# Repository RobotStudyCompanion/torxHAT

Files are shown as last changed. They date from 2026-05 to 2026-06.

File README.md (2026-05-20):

# torxHat

This repository contains the PCB design files for **torxHat** developed for the Robotic Study Companion (RSC) platform.

This board was designed to reduce dependency on specific audio HATs, while supporting multiple audio HAT options it also offers USB power delivery and peripheral connectivity.



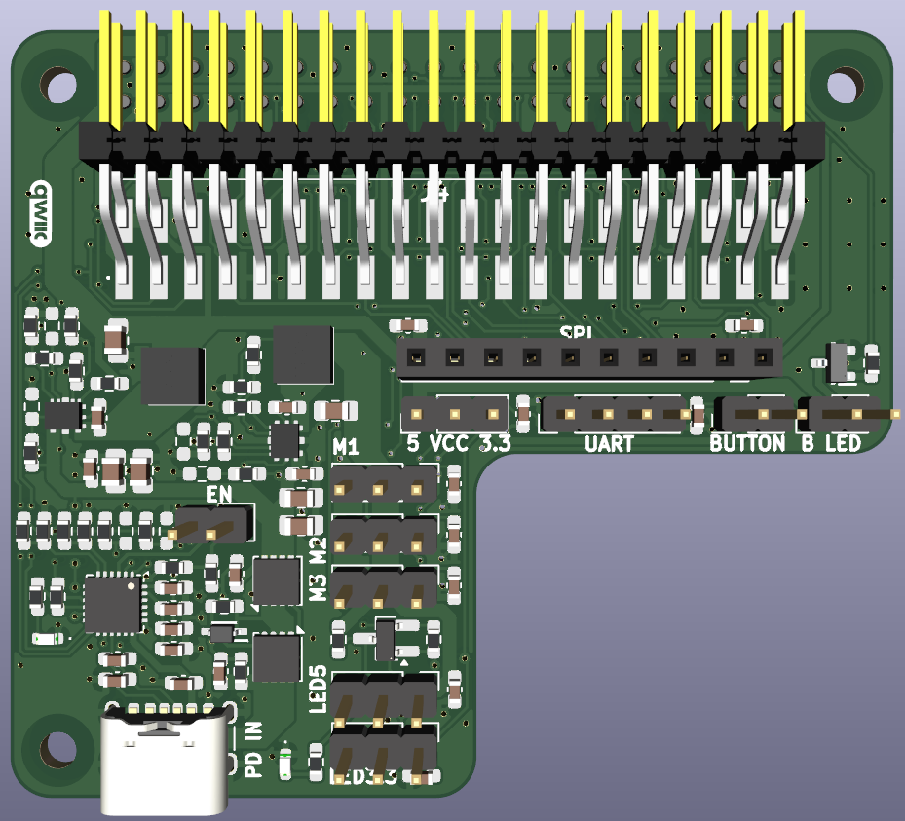
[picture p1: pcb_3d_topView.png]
torxHat_3D_view


---

## Design Summary
The PCB was designed in KiCad.

The board is powered from a single USB-C PD input configured for 20 V 2.5 A.

Power distribution is split into two independent 5.1 V rails:

* Logic rail for Raspberry Pi, audio hardware, and display
* High-current rail for servos and LED ring

The PCB is a compact two-layer Raspberry Pi HAT-compatible design with pass-through GPIO connectivity intended for audio HATs.

Audio HATs considered:

* AIY Voice Bonnet  
* ReSpeaker 2 Mics pHAT  
* WM8960 Audio HAT  
* AIY Voice HAT  
* Adafruit Voice Bonnet  
* Whisplay HAT  

---

## Author
Raiko Torga  
Supervised & reviewed by Matevž Borjan Zorec and Farnaz Baksh  
© Robotic Study Companion 2026

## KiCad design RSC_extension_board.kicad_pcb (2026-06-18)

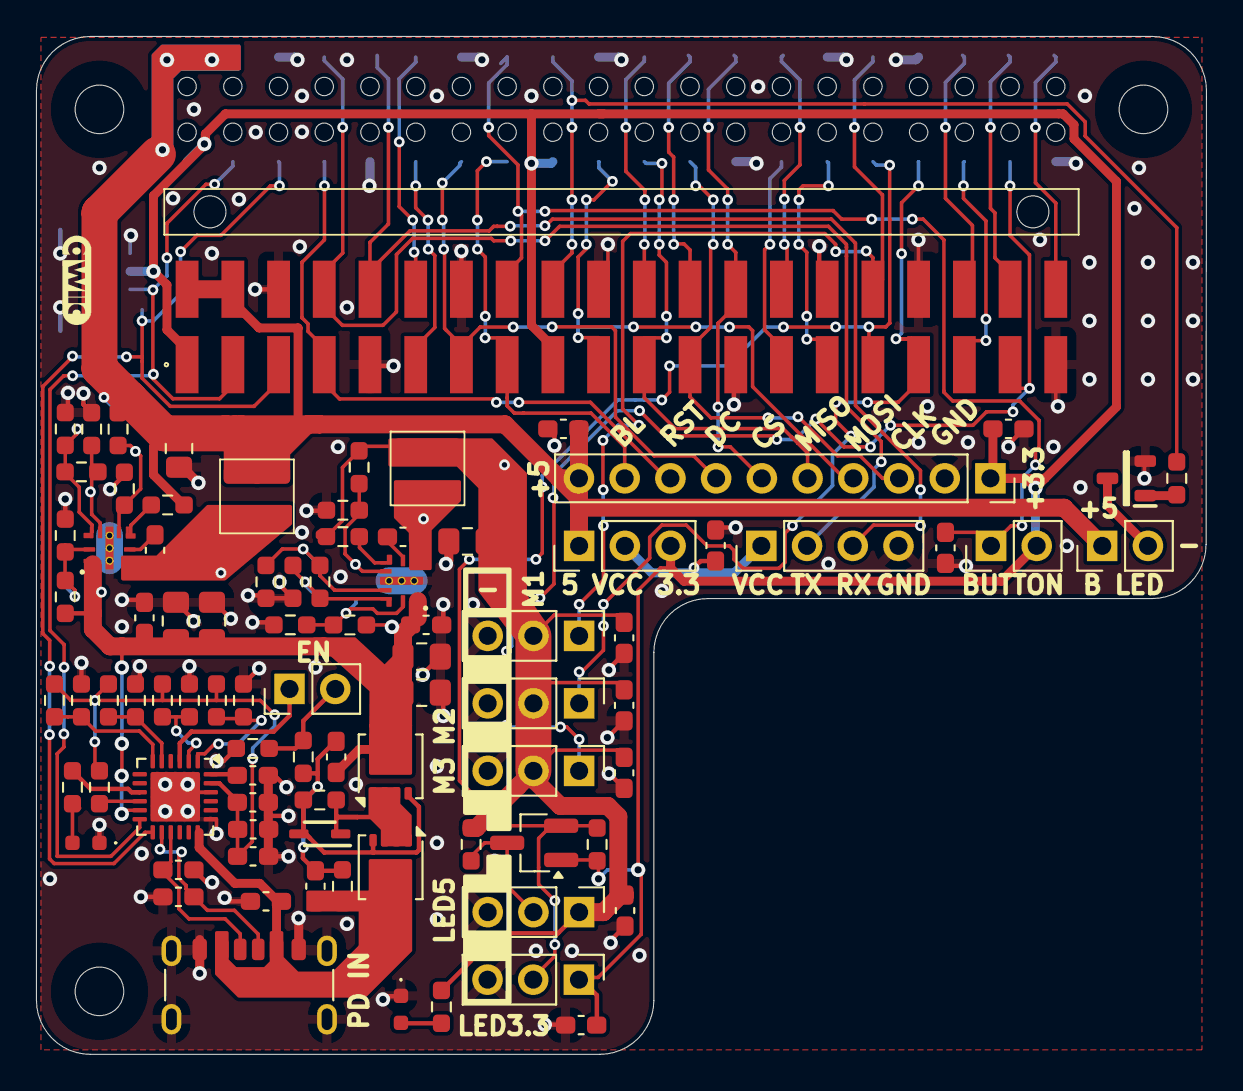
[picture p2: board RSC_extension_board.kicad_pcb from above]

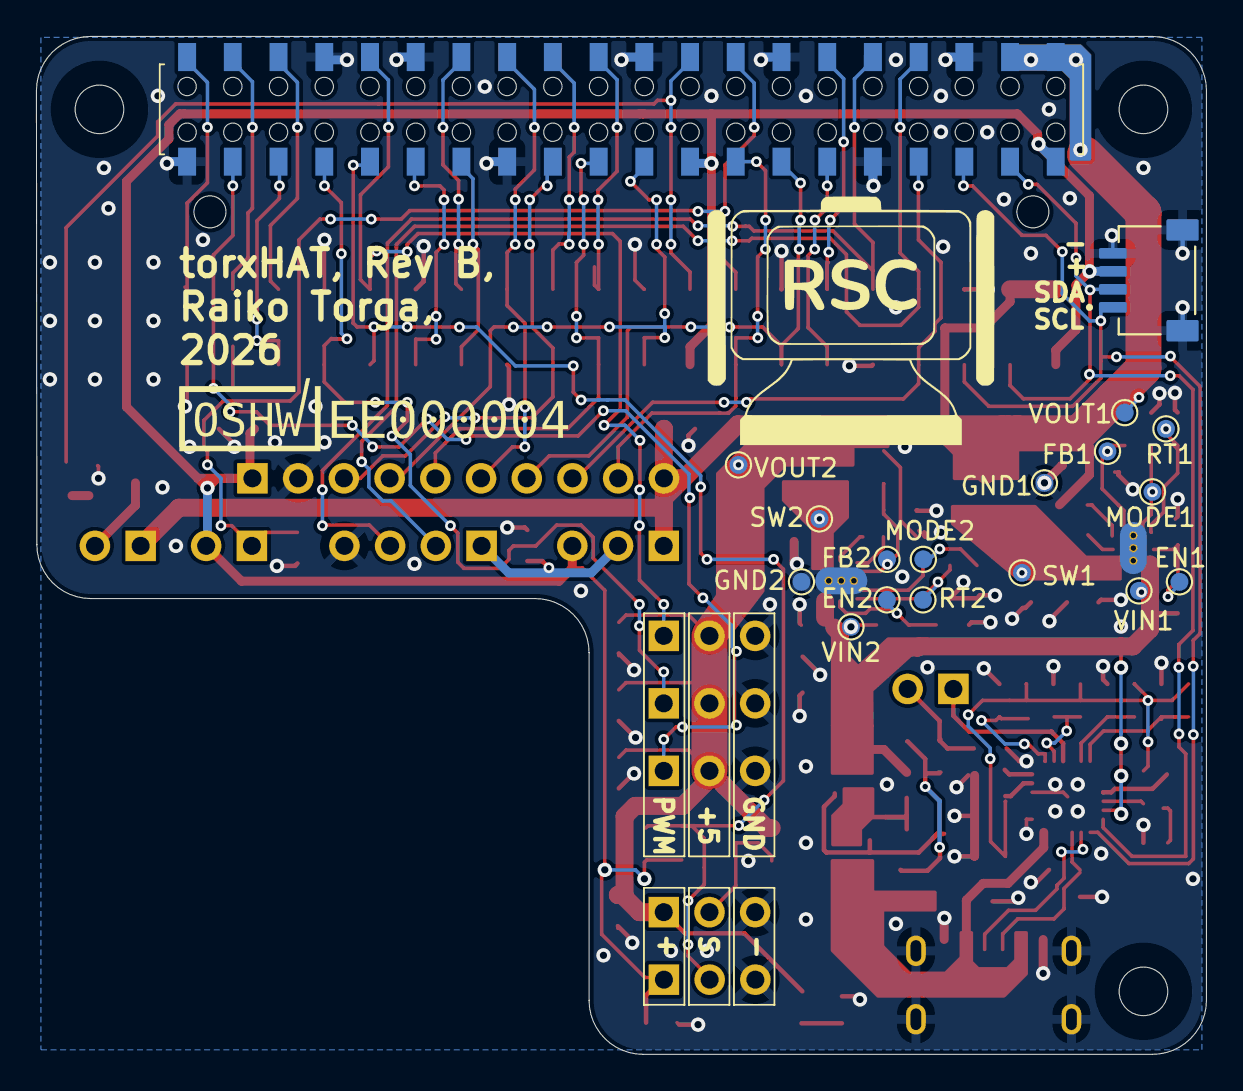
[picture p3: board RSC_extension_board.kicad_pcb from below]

Board: 2 copper layers, 65.0 x 56.5 mm, 106 parts (18 on the bottom side), 68 nets.

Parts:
C1, C2, C3, C4, C5, C6, C7, C8, C9, C41, C42, C43, C44, C53, C54: 100nF; C_0603_1608Metric_Pad1.08x0.95mm_HandSolder
C37, C38, C39, C40: 4.7uF; C_0805_2012Metric_Pad1.18x1.45mm_HandSolder
C45, C46: 22uF; C_0805_2012Metric_Pad1.18x1.45mm_HandSolder
C47, C49: 390pF; C_0603_1608Metric_Pad1.08x0.95mm_HandSolder
C48: 3.3uF; C_0603_1608Metric_Pad1.08x0.95mm_HandSolder
C50, C51, C52, C55: 1uF; C_0603_1608Metric_Pad1.08x0.95mm_HandSolder
D1: BAT54WS-7-F; SOD2513X120N
FPWM1, FPWM2: SHUNT; R_0603_1608Metric_Pad0.98x0.95mm_HandSolder
G1: qwiic_Logo; qwiic_5mm
J1: NPTC202KFMS-RC; NPTC202KFMSRC_bottomLayer
J2, J5: Conn_01x02; PinHeader_1x02_P2.54mm_Vertical
J4: TSM-120-02-F-DH; TSM-120-ZZ-YYY-DH-A-K-TR
J6, J7, J8, J11, J12: Conn_01x03; PinHeader_1x03_P2.54mm_Vertical
J9: PRT-14417; SPARKFUN_PRT-14417
J10: Conn_01x04; PinHeader_1x04_P2.54mm_Vertical
J13: Conn_01x10; PinSocket_1x10_P2.54mm_Vertical
J16: USB_C_Receptacle_PowerOnly_6P; USB_C_Receptacle_GCT_USB4125-xx-x-0190_6P_TopMnt_Horizontal
JP1: Jumper_3_Bridged12; PinHeader_1x03_P2.54mm_Vertical
JP2: Jumper_2_Bridged; PinHeader_1x02_P2.54mm_Vertical
L1, L2: 74438356015HT
LED1: KW_EELP41.RU-S1U1-3K6L-3X4X-5-R18; KWEELP41RUS1U13K6L3X4X5R18
LED2: KR_EELP41.22-Q1S1-36-A8J8-020-R18; KREELP4122Q1S136A8J8020R18
PFM1, PFM2: DNP; R_0603_1608Metric_Pad0.98x0.95mm_HandSolder
Q1: 2N7002-7-F; SOT96P240X120-3N
Q2: BSS138; SOT-23_Handsoldering
Q3, Q4: DMP3013SFV; Diodes_PowerDI3333-8
R1, R11, R17: 1k; R_0603_1608Metric_Pad0.98x0.95mm_HandSolder
R2: 150; R_0603_1608Metric_Pad0.98x0.95mm_HandSolder
R3, R4, R8: 10k; R_0603_1608Metric_Pad0.98x0.95mm_HandSolder
R5, R6, R7: 100k; R_0603_1608Metric_Pad0.98x0.95mm_HandSolder
R9, R12: 0; R_0603_1608Metric_Pad0.98x0.95mm_HandSolder
R10, R13: DNP; R_0603_1608Metric_Pad0.98x0.95mm_HandSolder
R14: 49k9; R_0603_1608Metric_Pad0.98x0.95mm_HandSolder
R15, R18: 5k1; R_0603_1608Metric_Pad0.98x0.95mm_HandSolder
R16, R19: 2k4; R_0603_1608Metric_Pad0.98x0.95mm_HandSolder
R20: 50k; R_0603_1608Metric_Pad0.98x0.95mm_HandSolder
RENB1, RENB2: DNP; R_0603_1608Metric_Pad0.98x0.95mm_HandSolder
RENT1, RENT2: SHUNT; R_0603_1608Metric_Pad0.98x0.95mm_HandSolder
RFBB1, RFBB2: 20k; R_0603_1608Metric_Pad0.98x0.95mm_HandSolder
RFBT1, RFBT2: 82k; R_0603_1608Metric_Pad0.98x0.95mm_HandSolder
RT1, RT2: 16k5; R_0603_1608Metric_Pad0.98x0.95mm_HandSolder
TP1: EN1; TestPoint_Pad_D1.0mm
TP2: EN2; TestPoint_Pad_D1.0mm
TP3: VIN1; TestPoint_Pad_D1.0mm
TP4: MODE1; TestPoint_Pad_D1.0mm
TP5: VIN2; TestPoint_Pad_D1.0mm
TP6: MODE2; TestPoint_Pad_D1.0mm
TP7: RT1; TestPoint_Pad_D1.0mm
TP8: RT2; TestPoint_Pad_D1.0mm
TP9: GND1; TestPoint_Pad_D1.0mm
TP10: GND2; TestPoint_Pad_D1.0mm
TP11: SW1; TestPoint_Pad_D1.0mm
TP12: SW2; TestPoint_Pad_D1.0mm
TP13: FB1; TestPoint_Pad_D1.0mm
TP14: FB2; TestPoint_Pad_D1.0mm
TP15: VOUT1; TestPoint_Pad_D1.0mm
TP16: VOUT2; TestPoint_Pad_D1.0mm
U3, U4: LMR604403SRAKR; QFN-9_2.5x2.0mm_RAK
U5: CYPD3177-24LQ; QFN-24-1EP_4x4mm_P0.5mm_EP2.75x2.75mm

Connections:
+3.3V: C2.1, C9.1, J1.1, J1.17, J2.2, J4.1, J4.17, J9.3, J12.1, J13.1, JP1.3 (B), Q2.1 (G), R3.1
+3.3V_PD: C52.2, C53.2, C54.2, R9.2, R12.2, R15.2, R18.2, R20.2, U5.23 (VDDD)
+5V_RPI: C3.1, C45.1, J1.2, J1.4, J4.2, J4.4, J5.1, J13.10, JP1.1 (A), L1.2, R5.2, RFBT1.1, TP15.1
+5V_Servo: C4.1, C5.1, C6.1, C8.1, C46.1, J6.2, J7.2, J8.2, J11.1, L2.2, R1.2, R4.1, R6.2, RFBT2.1, TP16.1
/BUTTON: C1.2, J1.16, J2.1, J4.16
/GPIO00: J1.27, J4.27
/GPIO01: J1.28, J4.28
/GPIO05: J1.29, J4.29
/GPIO08: J1.24, J4.24
/GPIO16: J1.36, J4.36
/GPIO17: J1.11, J4.11
/GPIO25: J1.22, J4.22
/I2S_BCLK: J1.12, J4.12
/I2S_DIN: J1.38, J4.38
/I2S_DOUT: J1.40, J4.40
/I2S_LRCLK: J1.35, J4.35
/LCD_BL: J1.15, J4.15, J13.9
/LED_3.3V: J1.31, J4.31, J12.2, Q2.2 (S), R3.2
/LED_5V: J11.2, Q2.3 (D), R4.2
/LED_PWM: J1.18, J4.18, R2.2
/M1_PWM: J1.32, J4.32, J6.1
/M2_PWM: J1.33, J4.33, J7.1
/M3_PWM: J1.37, J4.37, J8.1
/RX_3.3V: J1.10, J4.10, J10.3
/SCL: J1.5, J4.5, J9.1, U5.13 (HPI_SCL)
/SDA: J1.3, J4.3, J9.2, U5.12 (HPI_SDA)
/SPI_CLK: J1.23, J4.23, J13.3
/SPI_CS: J1.26, J4.26, J13.6
/SPI_DC: J1.13, J4.13, J13.7
/SPI_MISO: J1.21, J4.21, J13.5
/SPI_MOSI: J1.19, J4.19, J13.4
/SPI_RST: J1.7, J4.7, J13.8
/TX_3.3V: J1.8, J4.8, J10.2
GND: C1.1, C2.2, C3.2, C4.2, C5.2, C6.2, C7.2, C8.2, C9.2, C37.2, C38.2, C39.2, C40.2, C41.2, C42.2, C45.2, C46.2, C47.1, C48.1, C49.1, C50.1, C52.1, C53.1, C54.1, J1.6, J1.9, J1.14, J1.20, J1.25, J1.30, J1.34, J1.39, J4.6, J4.9, J4.14, J4.20, J4.25, J4.30, J4.34, J4.39, J6.3, J7.3, J8.3, J9.4, J9.S1, J9.S2, J10.4, J11.3, J12.3, J13.2, J16.A12 (GND), J16.B12 (GND), J16.S1 (SHIELD), LED1.1 (K), LED2.1 (K), PFM1.2, PFM2.2, Q1.2 (S), R7.1, R10.1, R13.1, R16.1, R19.1, RENB1.2, RENB2.2, RFBB1.2, RFBB2.2, RT1.2, RT2.2, TP9.1, TP10.1, U3.2 (PGND), U4.2 (PGND), U5.19 (GND), U5.22 (GND), U5.25 (GND)
unnamed: C51.1, C55.1, D1.2 (A), Q3.4 (G), Q4.4 (G), R8.1, R11.2, R14.1
unnamed: D1.1 (K), Q3.1 (S), Q3.2 (S), Q3.3 (S), Q4.1 (S), Q4.2 (S), Q4.3 (S), R14.2
unnamed: J5.2, Q1.3 (D)
unnamed: C7.1, J10.1, JP1.2 (C)
unnamed: C49.2, J16.A5 (CC1), U5.15 (CC1)
unnamed: C47.2, J16.B5 (CC2), U5.14 (CC2)
unnamed: JP2.1 (A), U5.3 (VBUS_FET_EN)
unnamed: JP2.2 (B), R7.2, R11.1
unnamed: LED1.2 (A), R1.1
unnamed: LED2.2 (A), R17.1
unnamed: Q1.1 (G), R2.1
unnamed: C48.2, C51.2, J16.A9 (VBUS), J16.B9 (VBUS), Q3.5 (D), R8.2, U5.18 (VBUS_IN)
unnamed: C43.1, U3.4 (BOOT)
unnamed: RENB1.1, RENT1.1, TP1.1, U3.9 (EN)
unnamed: RFBB1.1, RFBT1.2, TP13.1, U3.6 (FB)
unnamed: FPWM1.1, PFM1.1, TP4.1, U3.7 (MODE/SYNC)
unnamed: R5.1, U3.5 (PG)
unnamed: FPWM1.2, RT1.1, TP7.1, U3.8 (RT)
unnamed: C43.2, L1.1, TP11.1, U3.3 (SW)
unnamed: C44.1, U4.4 (BOOT)
unnamed: RENB2.1, RENT2.1, TP2.1, U4.9 (EN)
unnamed: RFBB2.1, RFBT2.2, TP14.1, U4.6 (FB)
unnamed: FPWM2.1, PFM2.1, TP6.1, U4.7 (MODE/SYNC)
unnamed: R6.1, U4.5 (PG)
unnamed: FPWM2.2, RT2.1, TP8.1, U4.8 (RT)
unnamed: C44.2, L2.1, TP12.1, U4.3 (SW)
unnamed: R17.2, U5.9 (FAULT)
unnamed: R20.1, U5.10 (FLIP)
unnamed: R15.1, R16.2, U5.5 (ISNK_COARSE)
unnamed: R18.1, R19.2, U5.6 (ISNK_FINE)
unnamed: R9.1, R10.2, U5.2 (VBUS_MAX)
unnamed: R12.1, R13.2, U5.1 (VBUS_MIN)
unnamed: C50.2, U5.24 (VCCD)
VBUS: C37.1, C38.1, C39.1, C40.1, C41.1, C42.1, C55.2, Q4.5 (D), RENT1.2, RENT2.2, TP3.1, TP5.1, U3.1 (VIN), U4.1 (VIN), U5.11 (VDC_OUT)

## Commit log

2025-11-04 changed raspberry connector footprint to https://ee.farnell.com/harwin/m20-7812045/connector-rcpt-40pos-2-54mm-2row/dp/3225919
    [RSC_extension_board.kicad_sch]
2025-11-04 added .stp file for raspi connector
    [RSC_extension_board.kicad_pcb]
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2025-11-05 added some tvs diodes. symbols weird
    [RSC_extension_board.kicad_pcb, RSC_extension_board.kicad_sch]
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2025-11-05 some external power stuff
    [RSC_extension_board.kicad_sch]
2025-11-09 bit of power circuit
    [RSC_extension_board.kicad_pcb, RSC_extension_board.kicad_sch]
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2025-11-12 qwiic connector and 3.3v led out
    [RSC_extension_board.kicad_pcb, RSC_extension_board.kicad_sch]
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2025-11-18 added possibility for button led dimming
    [RSC_extension_board.kicad_pcb, RSC_extension_board.kicad_sch]
2025-11-19 started possible voice schematic
    [RSC_extension_board.kicad_sch]
2025-11-20 bit of voice schematic
    [voice.kicad_sch]
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2025-11-20 voice schematic switch, 3d files
    [RSC_extension_board.kicad_pcb, RSC_extension_board.kicad_sch, voice.kicad_sch]
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2025-12-03 some new pins for raspberry gpio-s
    [RSC_extension_board.kicad_sch]
2025-12-03 Led_3.3 has also net
    [RSC_extension_board.kicad_sch]
2025-12-14 new power switch, added spi out
    [RSC_extension_board.kicad_sch]
2025-12-15 added power for spi
    [RSC_extension_board.kicad_sch]
2025-12-17 spi display pinout change. button connector simplified.
    [RSC_extension_board.kicad_pcb, RSC_extension_board.kicad_sch]
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2025-12-22 started designing pd in
    [RSC_extension_board.kicad_sch, voice.kicad_sch]
2025-12-22 20v 2a PD input
    [RSC_extension_board.kicad_sch]
2025-12-23 started 20v to 5v schematic
    [RSC_extension_board.kicad_sch]
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2026-01-03 some new ideas for power
    [RSC_extension_board.kicad_sch, USB_power.kicad_sch, buck_converter.kicad_sch]
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2026-01-06 annotation and pcb outline
    [RSC_extension_board.kicad_pcb, RSC_extension_board.kicad_sch, USB_power.kicad_sch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]
2026-01-06 new caps and bit of layout
    [RSC_extension_board.kicad_pcb, USB_power.kicad_sch, buck_converter.kicad_sch]
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2026-01-07 new bottom layer footprint for Pi connector
    [RSC_extension_board.kicad_pcb, RSC_extension_board.kicad_sch]
2026-01-07 rounded edges, new rules
    [RSC_extension_board.kicad_pcb]
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2026-01-09 added pi and piZero(or voice hat) outlines
    [RSC_extension_board.kicad_pcb]
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2026-01-19 20v to 5v 4A times two
    [USB_power.kicad_sch, buck_converter.kicad_sch]
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2026-01-21 buck converter test pads and optional resistors
    [RSC_extension_board.kicad_pcb, RSC_extension_board.kicad_sch, USB_power.kicad_sch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]
2026-01-25 some footprint for LMR60440
    [RSC_extension_board.kicad_pcb, RSC_extension_board.kicad_sch, USB_power.kicad_sch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]
2026-01-26 experimental 2x20 out for voice hat
    [RSC_extension_board.kicad_pcb, RSC_extension_board.kicad_sch]
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2026-01-28 DMP3013's for pd controller
    [USB_power.kicad_sch]
2026-01-28 playing around with 2x20 pin. no 3d on top one
    [RSC_extension_board.kicad_pcb, RSC_extension_board.kicad_sch]
2026-01-28 3d model for 90deg smd header
    [RSC_extension_board.kicad_pcb]
2026-02-01 bit of placement and started routing
    [RSC_extension_board.kicad_pcb]
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2026-02-03 L shaped layout. voice pins pushed inwards
    [RSC_extension_board.kicad_pcb]
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2026-02-05 experimental thermal pads on bottom side. pins for on/off switch.
    [RSC_extension_board.kicad_pcb, RSC_extension_board.kicad_sch, USB_power.kicad_sch]
2026-02-09 bit of layout. new LMR60440 footprint
    [RSC_extension_board.kicad_pcb, buck_converter.kicad_sch]
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2026-02-11 spi connector pin order. bit of routing
    [RSC_extension_board.kicad_pcb, RSC_extension_board.kicad_sch]
2026-02-12 new placement for buck converters
    [RSC_extension_board.kicad_pcb]
2026-02-12 user.drawing has L shaped edge.cut version
    [RSC_extension_board.kicad_pcb]
2026-02-14 all nets for headers
    [RSC_extension_board.kicad_pcb, RSC_extension_board.kicad_sch]
2026-02-16 smaller test pads. some routing
    [RSC_extension_board.kicad_pcb, buck_converter.kicad_sch]
2026-02-17 routing fixes
    [RSC_extension_board.kicad_pcb]
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2026-02-25 L shaped edge cut. PD controller and servo connectors got moved bit left
    [RSC_extension_board.kicad_pcb]
2026-02-25 pull down resistor on PD mosfet gates- for jumper
    [RSC_extension_board.kicad_pcb, RSC_extension_board.kicad_sch, USB_power.kicad_sch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]
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2026-03-01 test pads on board. gnd vias for islands
    [RSC_extension_board.kicad_pcb]
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2026-03-04 some drc fixes
    [RSC_extension_board.kicad_pcb]
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2026-03-04 fixed drc errors.
    [RSC_extension_board.kicad_pcb]
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2026-03-15 some fixes with vias
    [RSC_extension_board.kicad_pcb]
2026-03-16 vias not on pads. PD controller slightly lower
    [RSC_extension_board.kicad_pcb]
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2026-03-26 generic 2.54mm headers and testPads excluded from BOM
    [RSC_extension_board.kicad_pcb, RSC_extension_board.kicad_sch, USB_power.kicad_sch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]
2026-04-14 J4 connector had correct footprint but false component name
    [RSC_extension_board.kicad_pcb, RSC_extension_board.kicad_sch]
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2026-05-19 correct feedback resistors on buck converters
    [RSC_extension_board.kicad_pcb, RSC_extension_board.kicad_sch, USB_power.kicad_sch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]
2026-06-01 Started Rev B: white power LED, USB slightly over edge
    [RSC_extension_board.kicad_pcb, RSC_extension_board.kicad_sch, USB_power.kicad_sch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]
2026-06-02 new logo. lmr has 1st pin marking. pinout on silkscreen.
    [RSC_extension_board.kicad_pcb]
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

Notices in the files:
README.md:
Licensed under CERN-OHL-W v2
